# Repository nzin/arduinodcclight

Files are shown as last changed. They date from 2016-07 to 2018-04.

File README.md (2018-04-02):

View this project on [CADLAB.io](https://cadlab.io/node/818). 

A versatile Arduino stationary dcc decoder
==========================================

arduino dcc Arduino DCC

When constructing my dcc based train model, I looked for dcc decoder to pilot light (SMD 0402, or standard led), but had difficulty to program them for custom scenario (blinking, road works style, …). There are also some DIY dcc decoder (opendcc decoder) but didn’t manage to make them working. So I decided to create my own stationary dcc decoder based on Arduino (nano), to be able to reprogram it at wish.

This decoder is pretty simple, you can
 * assign it a dcc address (via a learning switch button)
 * connect LED lights, or a relay
 * choose the light mode if you connected lights. There are 3 different modes you can choose via a push button: constant light (on or off), flicker mode, or 3 way road work lights mode

It has been designed to be powered by a 16V AC, but can be as well be powered via DCC signal (15v or 18v), or a DC signal.

Using it
========

arduino dcc usage Arduino DCC Usage

Powering
--------
This decoder is designed to be powered by a 16V AC power source. It is possible to power it with the dcc signal, but my circuit is not the most power efficient stationary decoder (due to the fact that it power lights, an arduino and eventually a relay), so you don’t want that, except in rare situation.

This is why there are 2 set of cables:
 * one for the 16V AC
 * one for the DCC signal

Assign a dcc address
--------------------

To assign a dcc address, you have to use the learning switch opposite to the Arduino.
In that position, each time it see a stationary decoder command coming on, it will store it as its new address (and will acknowledge that by blinking the status led).
So to assign a dcc address you just have to
 * push the learning switch opposite to the Arduino.
 * send a command with the wished address
 * you will see the status led blinking, stating that it saw the address and learned it
 * push back the learning switch towards the Arduino

Connect light
-------------

On the bottom of the card, you have 3 slots for leds. The + of the led must be on the left. Normaly you can connect only one led per slot (due to the nominal tension that each led has, 2 different led don't have the exact same nominal tension).

If you use the push button, you will circle between 3 modes:
 * constantly on (or off)
 * flickering seldomly
 * 3 way road work lights (it will switch on the first light, then the second light, then the 3rd light, and cycle again to the first light)

You just has to use the push button to cycle between the 3 modes. The little status led, will tell you in which mode you are.

Connect relay
-------------

Close to the lights there is a block of 3 pins for the relay (if you decide to build it), which are in this order: low ouput, input, high output.
So the one on the middle is your input (whatever your input is), and the relay will connect it either to the left pin or to the right pin.

Connect to the other IO
=======================

arduino dcc usage Arduino DCC Usage

There are some generic IO available, that expose
 * 5v and ground
 * analog pins 6 and 7
 * and digital pins 6 and 7

You can use them at your own advantage, but you will need to reprogram the Arduino to you own purpose: I didn’t program anything on them.

Assemble it
===========

If you don’t want to assemble, or just want the PCB already fabricated, contact me, and I can provide it for you: nicolas.zin@gmail.com

If you prefer to fully assemble it, you will need to get the PCB, and of course the components.
The PCB gerber files are here: https://github.com/nzin/arduinodcc/blob/master/arduinov1.2.zip (for the eagle source check below)

To fully assemble it, the full Bill Of Material is:

item                    |how many |ref
------------------------|---------|------------------------------------
arduino nano            |1        |aliexpress
bridge rectifier        |1        |mouser 625-B40C800G-E4
DC-DC converter (9VDC)  |1        |mouser 490-V7809-1000 (or cheaper : voltage regulator mouser 511-L7809CV in that case buy also a heatsink)
capa 330uF              |1        |mouser 667-EEU-FM1C331
capa 10uF               |1        |mouser 581-TAP106K025SCS
R 10k ohm               |4        |mouser 71-CCF50-10K
R 1k ohm                |1        |mouser 603-CFR-12JR-521K
diode 4148              |1        |mouser 512-1N4148
toggle button           |1        |sparkfun COM-00102 (maybe mouser 633-SS12SDP2)
push button             |1        |SPARKUN COM-00097 (ou mouser 693-1301.9308)
led                     |1        |mouser 941-C4SMFRJSCT0W0BB2 (or 630-HLMP-1301)
terminal block  2 pos   |10       |mouser 651-1729128
headers                 |2        |mouser 855-M20-7821546
high speed optocoupler  |1        |mouser 630-6N137
R 200 ohm               |9        |mouser 71-CCF50-200
shottky diode           |1        |mouser 833-SR108-TP

logical schema Eagle physical schema

Reprogram it
============

If you are familiar with Arduino programming, you can re-program it to whatever needs you have. That the beauty of it. Here are the arduino sources: https://github.com/nzin/arduinodcc/blob/master/arduinoSource/dccduino.ino

It is based on the dcc decoder library from Minabay you will need to install: https://github.com/MynaBay/DCC_Decoder

Extend it
=========

If you want to develop your own dcc decoder, I provide you the eagle source: https://github.com/nzin/arduinodcc/blob/master/arduinoDcc1.2.sch and https://github.com/nzin/arduinodcc/blob/master/arduinoDcc1.2.brd

Feel free to adapt it to your needs, but I provide it as is, i.e. I can answer some question but if you decide to change the layout, you are on your own

logical schema Eagle logical schema

Licence
=======
The Arduino code and the Eagle schema are under the [GPL v2](https://github.com/nzin/arduinodcc/blob/master/gpl-2.0.txt)

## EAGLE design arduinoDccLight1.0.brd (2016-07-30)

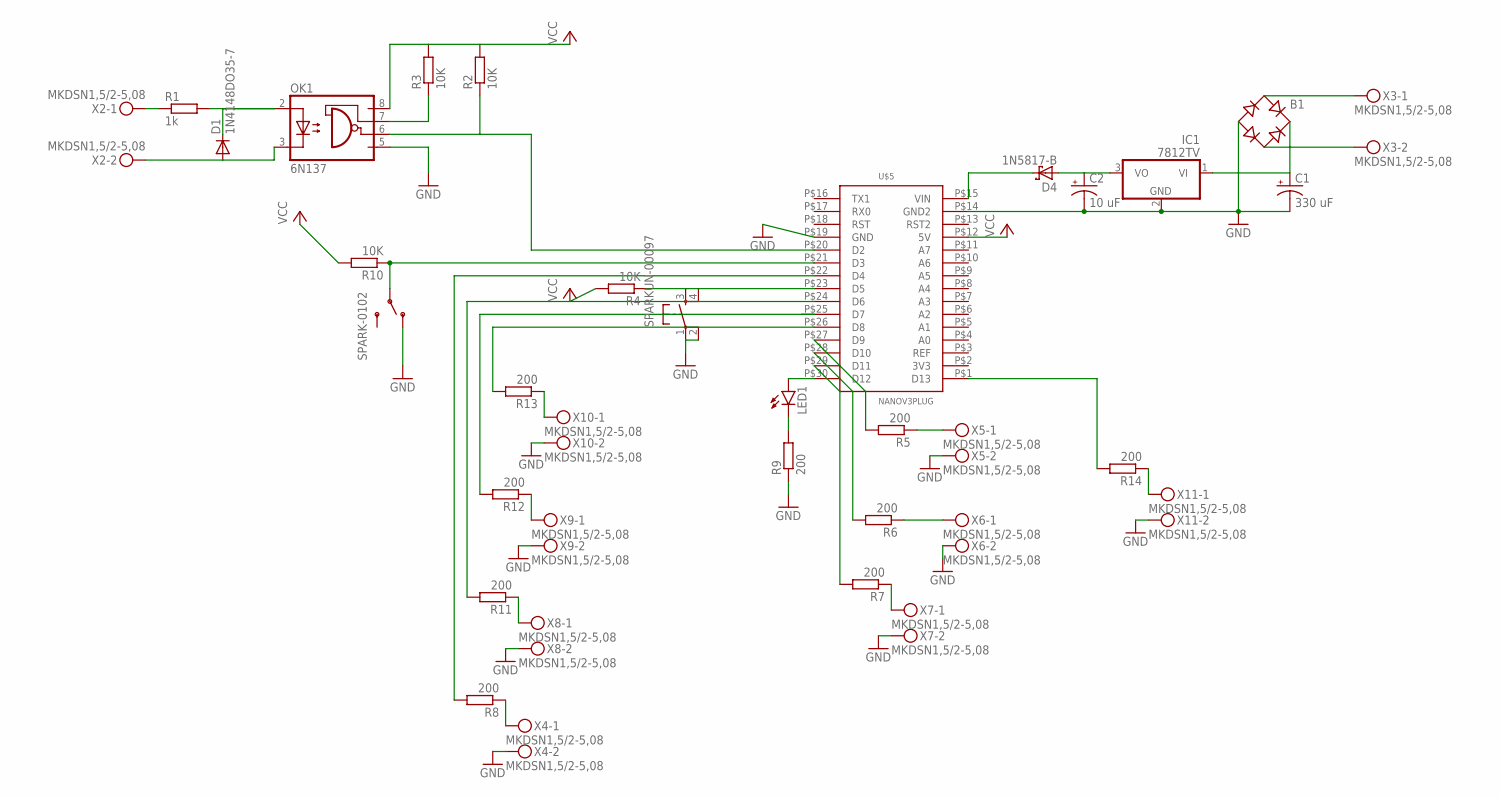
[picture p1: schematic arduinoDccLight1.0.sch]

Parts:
B1: RB1A
C1: 330 uF; CPOL-RADIAL-100UF-25V
C2: 10 uF; CPOL-RADIAL-100UF-25V
D1: 1N4148DO35-7; DO35-7
D4: 1N5817-B; DO41-7.6
IC1: 7812TV; TO220V
LED1: LED3MM
OK1: 6N137; DIL08
R1: 1k; 0207/10
R2, R3, R4, R10: 10K; 0207/10
R5, R6, R7, R8, R11, R12, R13, R14: 200; 0207/10
R9: 200; 0204/7
SPARK-0102: SWITCH-SPDTPTH; SWITCH-SPDT
SPARKUN-00097: TAC_SWITCHPTH; TACTILE-PTH
U$5: NANOV3PLUG; HEADER15-2
X2, X3, X4, X5, X6, X7, X8, X9, X10, X11: MKDSN1,5/2-5,08

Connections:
GND: B1.-, C1.2 (-), C2.2 (-), IC1.2 (GND), OK1.5 (GND), R9.1, SPARK-0102.1 (O), SPARKUN-00097.1, SPARKUN-00097.2, U$5.P$14 (GND2), U$5.P$19 (GND), X4.2, X5.2, X6.2, X7.2, X8.2, X9.2, X10.2, X11.2
unnamed: R1.1, X2.1
unnamed: D1.C, OK1.2 (A), R1.2
unnamed: D1.A, OK1.3 (C), X2.2
unnamed: R10.1, SPARK-0102.2, U$5.P$21 (D3)
unnamed: R8.1, X4.1
unnamed: OK1.6 (VO), R2.1, U$5.P$20 (D2)
unnamed: OK1.7 (VE), R3.1
unnamed: B1.AC1, X3.1
unnamed: R8.2, U$5.P$22 (D4)
unnamed: R11.1, X8.1
unnamed: R11.2, U$5.P$24 (D6)
unnamed: R12.1, X9.1
unnamed: R6.1, X6.1
unnamed: R7.2, U$5.P$29 (D11)
unnamed: R6.2, U$5.P$28 (D10)
unnamed: R5.2, U$5.P$27 (D9)
unnamed: R5.1, X5.1
unnamed: R4.1, SPARKUN-00097.3, SPARKUN-00097.4, U$5.P$23 (D5)
unnamed: R12.2, U$5.P$25 (D7)
unnamed: R13.1, X10.1
unnamed: R13.2, U$5.P$26 (D8)
unnamed: B1.AC2, X3.2
unnamed: B1.+, C1.1 (+), IC1.1 (VI)
unnamed: LED1.K (C), R9.2
unnamed: LED1.A, U$5.P$30 (D12)
unnamed: R7.1, X7.1
unnamed: C2.1 (+), D4.A, IC1.3 (VO)
unnamed: R14.1, X11.1
unnamed: R14.2, U$5.P$1 (D13)
unnamed: D4.C, U$5.P$15 (VIN)
VCC: OK1.8 (VCC), R2.2, R3.2, R4.2, R10.2, U$5.P$12 (5V)

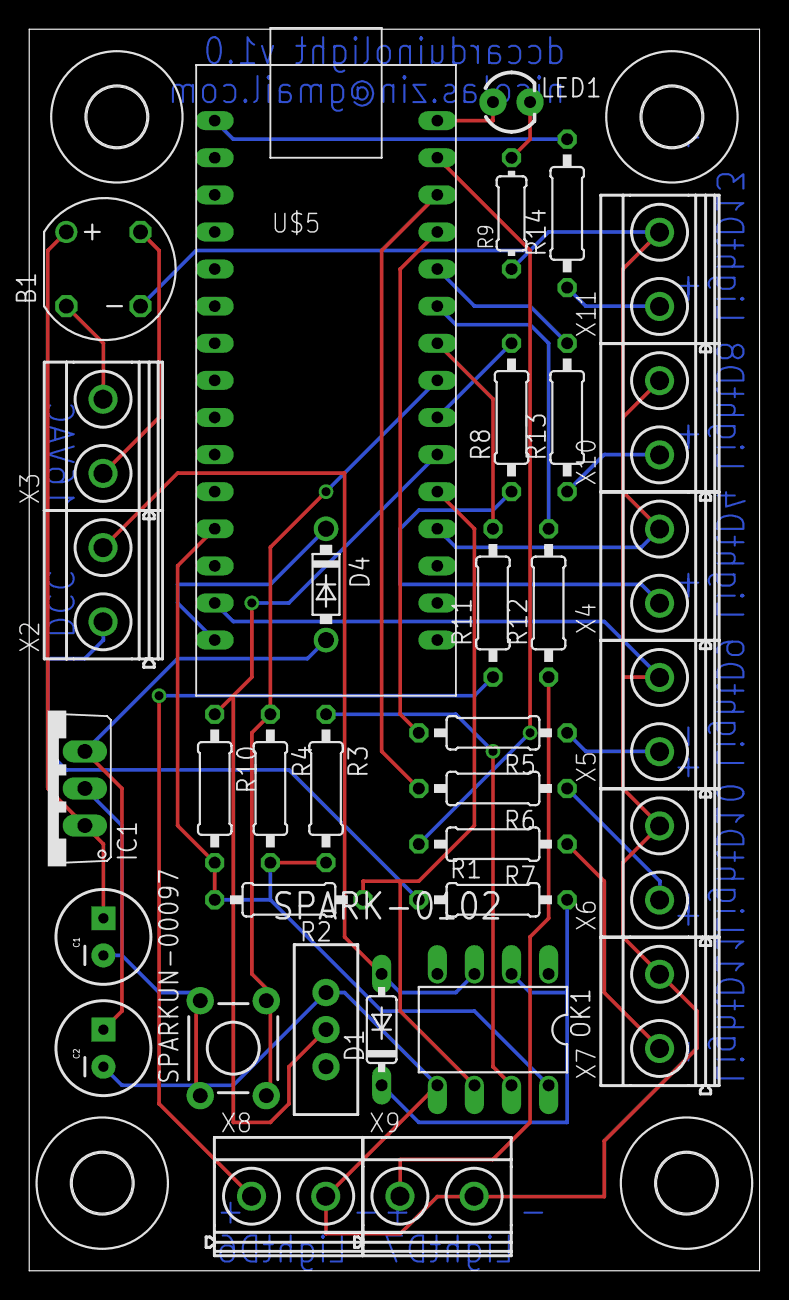
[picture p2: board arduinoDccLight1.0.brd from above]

Board: 2 copper layers, 50.0 x 85.0 mm, 39 parts (0 on the bottom side), 32 nets.

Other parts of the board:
U$1, U$2, U$3, U$4: 4,1

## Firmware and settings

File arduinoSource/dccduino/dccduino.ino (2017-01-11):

#include "DCC_Decoder.h"
#define kDCC_INTERRUPT            0


#include <EEPROM.h>
#define EEPROM_LIGHTMODE 0     // we store the last "light mode" selected by the user (via the push button)
#define EEPROM_SWITCHSTATUS 1  // we store the last switch status (send via dcc)
#define EEPROM_ADDRESS 2  // we store our dcc address

#define LIGHT0 13
#define LIGHT1 8
#define LIGHT2 4
#define LIGHT3 9
#define LIGHT4 10
#define LIGHT5 11
#define LIGHT6 7
#define LIGHT7 6
#define LEDCONTROL 12 
#define PUSHBUTTON 5
#define LEARNINGBUTTON 3

#define MAXLIGHTMODE 2 // mode0=continuous, mode1=flicketing, mode2=roundrobin
int lightMode=0;
int switchStatus=HIGH;
int learningMode=LOW;



/**
 * this is just a function to show via the onboard PCB led, the state of the decoder
 */
void showAcknowledge(int nb) {
  for (int i=0;i<nb;i++) {
    digitalWrite(LEDCONTROL, HIGH);   // turn the LED on (HIGH is the voltage level)
    delay(100);               // wait for a second
    digitalWrite(LEDCONTROL, LOW);    // turn the LED off by making the voltage LOW
    delay(100);               // wait for a second
  }
}




/**
 * work done on connected lights depending on their state
 */
void treatLight(int switchStatus,int lightMode) {
  static int valLight[8]={0,0,0,0,0,0,0,0};
  static int blink=-1;
  static int chain=0;
  
  int tmp;
  
  switch (lightMode) {
    /*
     * mode 0:
     * - switch status = HIGH: we switch on the light in a fading in way.
     * - switch status = LOW: we switch off the light in a fading off way.
     */
    case 0:
      if (switchStatus==HIGH) {
        for (int i=0;i<8;i++) if (valLight[i]<255) valLight[i]+=5;
      } else {
        for (int i=0;i<8;i++) if (valLight[i]>0) valLight[i]-=5;
      }
      break;
    /*
     * mode 1:
     * - switch status = HIGH: we switch on the light in a fading in way.
     * - switch status = LOW: we switch off the light in a fading off way.
     * BUT randomly (1% of the time), we switch off a light and switch on it just after, to flicker it
     */
    case 1:
      if (switchStatus==HIGH) {
        for (int i=0;i<8;i++) if (valLight[i]<255) valLight[i]+=5;
      } else {
        for (int i=0;i<8;i++) if (valLight[i]>0) valLight[i]-=5;
      }
      
      /* 1% chance to flicker 1 of the 3 lights */
      if ((blink=random(100))<3) {
        tmp=valLight[blink];
        valLight[blink]=0;
        analogWrite(LIGHT0,valLight[0]);
        analogWrite(LIGHT1,valLight[1]);
        analogWrite(LIGHT2,valLight[2]);
        analogWrite(LIGHT3,valLight[3]);
        analogWrite(LIGHT4,valLight[4]);
        analogWrite(LIGHT5,valLight[5]);
        analogWrite(LIGHT6,valLight[6]);
        analogWrite(LIGHT7,valLight[7]);
        delay(50);
        valLight[blink]=tmp;
      }
      break;
    /*
     * mode 2: we switch on the first light, then the second light, then the 3rd light
     */
    case 2:
      chain++;
      if (chain==10) {
        valLight[0]=0;
        valLight[1]=255;
      } else if (chain==20) {
        valLight[1]=0;
        valLight[2]=255;
      } else if (chain==30) {
        valLight[2]=0;
        valLight[3]=255;
      } else if (chain==40) {
        valLight[3]=0;
        valLight[4]=255;
      } else if (chain==50) {
        valLight[4]=0;
        valLight[5]=255;
      } else if (chain==60) {
        valLight[5]=0;
        valLight[6]=255;
      } else if (chain==70) {
        valLight[6]=0;
        valLight[7]=255;
      } else if (chain==80) {
        valLight[7]=0;
        valLight[0]=255;
        chain=0;
      }
      break;
  }
  analogWrite(LIGHT0,valLight[0]);
  analogWrite(LIGHT1,valLight[1]);
  analogWrite(LIGHT2,valLight[2]);
  analogWrite(LIGHT3,valLight[3]);
  analogWrite(LIGHT4,valLight[4]);
  analogWrite(LIGHT5,valLight[5]);
  analogWrite(LIGHT6,valLight[6]);
  analogWrite(LIGHT7,valLight[7]);
}



/**
 * when a DCC packet is received, this function is called
 * for our needs, we decode the address:
 * - if we are in learning mode, we store this address as our new address
 * - if we are in normal mode, we switch on, or off light, depending on the "enable" state command
 */
void BasicAccDecoderPacket_Handler(int address, boolean activate, byte data)
{
  // Convert NMRA packet address format to human address
  address -= 1;
  address *= 4;
  address += 1;
  address += (data & 0x06) >> 1;
    
  int enable = (data & 0x01) ? HIGH : LOW;
    
  // if we are in learning mode, we store our dcc address
  if (learningMode==HIGH) {
    EEPROM.write(EEPROM_ADDRESS,address%256);
    EEPROM.write(EEPROM_ADDRESS+1,address/256);
    showAcknowledge(3);
  } else {
    // if we are in normal mode, then... we act accordingly
    int myaddress=EEPROM.read(EEPROM_ADDRESS)+(EEPROM.read(EEPROM_ADDRESS+1)*256);
    if (myaddress==address) {
      switchStatus=enable;
      EEPROM.write(EEPROM_SWITCHSTATUS,switchStatus);
    }
    /*
     * special case:
     * if our address is < 1000 we consider we are a light decoder.
     * if we receive order 'enable' on address 1000, we enter into "night mode"
     * if we receive order 'disable' on address 1000, we came back to our previous mode
     
    if (address==1000) {
      if (enable) {
        switchStatus=enable
      }
    }*/
  }
}



/*
 * standard arduino initialisation function
 * we initialize lights, button
 */
void setup() {
  // put your setup code here, to run once:
  pinMode(LIGHT0, OUTPUT);
  pinMode(LIGHT1, OUTPUT);
  pinMode(LIGHT2, OUTPUT);
  pinMode(LIGHT3, OUTPUT);
  pinMode(LIGHT4, OUTPUT);
  pinMode(LIGHT5, OUTPUT);
  pinMode(LIGHT6, OUTPUT);
  pinMode(LIGHT7, OUTPUT);
  pinMode(LEDCONTROL, OUTPUT);
  pinMode(PUSHBUTTON, INPUT);
  pinMode(LEARNINGBUTTON,INPUT);
  
  lightMode=EEPROM.read(EEPROM_LIGHTMODE);
  if (lightMode>MAXLIGHTMODE) lightMode=0;
  switchStatus=EEPROM.read(EEPROM_SWITCHSTATUS);
  if (switchStatus!=HIGH && switchStatus!=LOW) switchStatus=HIGH;
  
  showAcknowledge(lightMode+1);
  randomSeed(analogRead(A3));
  
  DCC.SetBasicAccessoryDecoderPacketHandler(BasicAccDecoderPacket_Handler, true);
//  ConfigureDecoder();
  DCC.SetupDecoder( 0x00, 0x00, kDCC_INTERRUPT );
}



void loop() {
  static int pushbuttonOldval=0,pushbuttonVal=0;
  static int learningbuttonOldval=0,learningbuttonVal=0;
  static unsigned long timer=0;
  
  ////////////////////////////////////////////////////////////////
  // Loop DCC library
  DCC.loop();
  
  ////////////////////////////////////////////////////////////////
  // check if the push button has been pressed
  pushbuttonVal=digitalRead(PUSHBUTTON);
  if (pushbuttonVal==LOW && pushbuttonOldval!=pushbuttonVal) {
    lightMode++;
    if (lightMode>MAXLIGHTMODE) lightMode=0;
    EEPROM.write(EEPROM_LIGHTMODE,lightMode);
    showAcknowledge(lightMode+1);
  }
  pushbuttonOldval=pushbuttonVal;
  
  ////////////////////////////////////////////////////////////////
  // check if the learning button has been enabled
  learningbuttonVal=digitalRead(LEARNINGBUTTON);
  if (learningbuttonOldval!=learningbuttonVal) {
    learningMode=learningbuttonVal;
    if (learningMode==HIGH) showAcknowledge(3);
  }
  learningbuttonOldval=learningbuttonVal;
  
  ////////////////////////////////////////////////////////////////
  // check if we have light to change from state
  if (millis()-timer>50) {
    treatLight(switchStatus,lightMode);
    timer=millis();
  }
}

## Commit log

2017-01-06 update BOM
2017-01-06 shottky diode
2017-01-11 remove relay related code, and fix a bug
    [dccduino.ino]
2017-01-11 put the light in the PCB order
2017-02-08 refresh BOM

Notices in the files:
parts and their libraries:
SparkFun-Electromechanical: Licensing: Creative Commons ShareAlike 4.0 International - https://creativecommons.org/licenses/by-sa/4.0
